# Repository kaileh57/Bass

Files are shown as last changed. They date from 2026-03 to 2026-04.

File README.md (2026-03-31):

This is a precision fender-style electric bass designed by me!

It's got three knobs for volume, treble and bass, as well as a custom PCB for active sound managment, and a dual amp system to play audio to EITHER a 1/4" jack OR a standard 3.5mm headphone jack. 
It also has a small rechargable battery to let me play with my headphones away from an amp or power source for hopefully a few hours at a time. 

The bass is pretty standard, and if you wanna 3d print the two parts, buy all the components, the wiring diagram should get you through the complex part!

I made this as I don't currently have an electric bass to play on, and would really like the chance to make my own instrument and start playing new types of music!

Here's what it looks like assembled:



The PCB



Wiring diagram:


The bom can be found in the bom.csv!

This was made (JUST IN TIME) for hack clubs blueprint program, which has been awesome!

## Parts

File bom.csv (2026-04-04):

Part Name | Quantity | Price (USD) | Source | Link | Notes
JLCPCB PCB Order (90x80mm 2-layer FR4 x5) | 1 | $7.18 | JLCPCB | https://jlcpcb.com/ | Incl. shipping + tax. Global Standard Direct Line
OPA2134PA DIP-8 (U1) | 1 | $6.98 | LCSC | https://www.lcsc.com/product-detail/C1346118.html?
NJM4556AD DIP-8 (U2) | 1 | $0.51 | LCSC | https://www.lcsc.com/product-detail/C2838125.html
TLE2426CLP TO-92 (U3) | 1 | $3.36 | Digikey | https://www.digikey.com/en/products/detail/texas-instruments/TLE2426CLP/276234
DIP-8 IC Sockets | 2 | $1.84 | LCSC | https://www.lcsc.com/product-detail/C2874007.html | For U1 and U2
1N5819 Schottky Diode DO-41 (D1) | 1 | $0.59 | LCSC | https://www.lcsc.com/product-detail/C402218.html | Reverse polarity protection
100uH Radial Power Inductor (L1) | 1 | $1.54 | LCSC | https://www.lcsc.com/product-detail/C5119631.html | Drum-core. 200mA+ sat current. DCR under 2 ohm
Resistor 0R axial (R_in_prot + R_damp) | 2 | $8.17 | LCSC | Kit: https://www.aliexpress.us/item/3256806831693280.html | Wire links. 1/4W axial through-hole
Resistor 2.2R axial (R_stab) | 1 | Included | LCSC |  | 1/4W metal film
Resistor 10R axial (R8 + R11) | 2 | Included | LCSC |  | 1/4W metal film
Resistor 100R axial (R2 + R_bias) | 2 | Included | LCSC |  | 1/4W metal film
Resistor 2.2K axial (R_LED) | 1 | Included | LCSC |  | 1/4W metal film
Resistor 10K axial (x10) | 10 | Included | LCSC |  | R_flat_in/fb R_treble1/2 R_fb1/2 R_gain1/2 R_bleed1/2
Resistor 22K axial (x3) | 3 | Included | LCSC |  | R_bass1/2 R_treble3
Resistor 470K axial (x2) | 2 | Included | LCSC |  | R_bias_hp1/2
Resistor 1M axial (R1) | 1 | Included | LCSC |  | Buffer input bias
100nF Ceramic Disc Cap 50V (x6) | 6 | $1.38 | AliExpress | https://www.aliexpress.us/item/3256805724293323.html | C2 C4 C_byp_U1 C_byp_U2 C_vref_U1 C_vref_U2. 5mm pitch
1nF Ceramic Disc Cap (C_bias) | 1 | $1.63 | AliExpress | https://www.aliexpress.us/item/3256802327709422.html | 5mm pitch, 1000pf
100uF 25V Electrolytic Radial (x3) | 3 | $0.56 | LCSC | https://www.lcsc.com/product-detail/C47344175.html | C1 C_pwr_U1 C_pwr_U2. 3.5mm pitch
1000uF 10V Electrolytic Radial (C3) | 1 | $0.61 | LCSC | https://www.lcsc.com/product-detail/C49256787.html | VREF reservoir. 5mm lead spacing
470uF 10V Electrolytic Radial (x2) | 2 | $0.78 | LCSC | https://www.lcsc.com/product-detail/C51904456.html | C_hp_out1 C_hp_out2. 5mm pitch
1uF Film Cap (x3) | 3 | $4.20 | AliExpress | https://www.aliexpress.us/item/3256806983416179.html | C_in C_hp_in1 C_hp_in2. 5mm pitch polyester, Color: 100v 0.1uF 5P
1nF Film Cap (C_treble) | 1 | $1.53 | AliExpress | https://www.aliexpress.us/item/3256808657561743.html | Treble wiper series cap. 5mm pitch
2.2uF Film Cap (C_vol) | 1 | $4.26 | AliExpress | https://www.aliexpress.us/item/3256803936423484.html | EQ output AC coupling. 10mm ish pitch
47nF Film Cap (C_bass) | 1 | $2.98 | AliExpress | https://www.aliexpress.us/item/3256808657558959.html | OFF-BOARD: soldered across bass pot lugs pin1-pin3
Pin Header Strip 1x40 2.54mm | 1 | $0.74 | LCSC | https://www.lcsc.com/product-detail/C2337.html | Cut to size for 9 connectors (26 pins total)
MT3608 DC-DC Boost Converter Module | 1 | $4.33 | AliExpress | https://www.aliexpress.us/item/3256811342611791.html | Boosts 3.7V to 9V.
TP4056 USB-C Li-Ion Charging Module | 1 | $6.42 | AliExpress | https://www.aliexpress.us/item/3256807940520587.html | USB-C charger with protection.
18650 Battery Holder (single cell) | 1 | $2.11 | AliExpress | https://www.aliexpress.us/item/3256809280893834.html? | Single cell holder with wire leads
DPDT Toggle Switch ON-ON 6-pin | 1 | $3.73 | AliExpress | https://www.aliexpress.us/item/2251832829462679.html | Active/passive bypass. Measure dims before CAD
LED 3mm | 1 | $0.00 | I have LEDs |  | Power indicator. Off-board via header
Adhesive Copper Foil Tape | 1 | $2.64 | AliExpress | https://www.aliexpress.us/item/3256802931706214.html | EMI shielding for control cavity
22AWG Stranded Hookup Wire | 1 | $0.00 | From previous project |  | Off-board wiring: pots/pickup/jacks/switch/bridge ground
Seymour Duncan SPB-1 Vintage P-Bass Pickup | 1 | $99.00 | Amazon | https://www.amazon.com/Seymour-Duncan-SPB-1-Vintage-Split-coil/dp/B001FXQDVQ | Split-coil P-bass pickup
Gotoh 201B-4 Bass Bridge (Chrome) | 1 | $46.49 | Amazon | https://www.amazon.com/GOTOH-201B-4-4-String-Bridge-spacing/dp/B00FGUN948 | 4-string. Includes mounting screws
CTS 250K Audio Taper Pot (A250K) | 1 | $13.88 | Amazon | https://www.amazon.com/A250K-Standard-Potentiometer-Electric-Guitar/dp/B0DSW4B33P?s=musical-instruments | Volume pot. LONG SHAFT if 12mm body face
100K Linear Pot B100K (x2) | 2 | $9.99 | Amazon | https://www.amazon.com/TWTADE-Potentiometer-Single-Variable-Aluminum/dp/B07DHGR3ST | Bass + Treble EQ pots. Long shaft preferred
Switchcraft #L11 Mono 1/4in Output Jack | 1 | 6.99 | Amazon | https://www.amazon.com/Switchcraft-2-Conductor-Input-Circuit-Bushing/dp/B0049BMPFO | Line output. 3/8-32 thread. 9.53mm hole
3.5mm Panel Mount Stereo Jack | 1 | $5.99 | Amazon | https://www.amazon.com/BLLNDX-Stereo-Female-Headphone-Connector/dp/B09B7JKSQ1?s=electronics | Headphone output. Measure before finalizing CAD hole
Schaller S-Locks Strap Locks (Pair Chrome) | 1 | $32.49 | Amazon | https://www.amazon.com/Schaller-Locks-Guitar-Buttons-Chrome/dp/B07F7DSBYW | Size M 4.0mm thread for PA6-CF body
Fender-Style Bass Neck Plate (4-bolt) | 1 | $11.49 | Amazon | https://www.amazon.com/Fender-4-Bolt-Vintage-Style-Plate-Plain/dp/B0002KZF8U | Distributes bolt force on 3D-printed body
18650 Li-Ion Battery | 1 | $7.74 | AliExpress | https://www.aliexpress.us/item/3256811753613609.html | 3.7V rechargeable.
Bass Guitar Strings 45-105 | 1 | $0.00 | Will get in person |  | Standard 34in scale roundwound
Pot Knobs 1/4in Solid Shaft (set of 3+) | 1 | $7.64 | Amazon | https://www.amazon.com/gonymask-Control-Telecaster-PaulGuitar-Accessories/dp/B0F64W28K5 | For volume + bass + treble pots
M3 Heat-Set Inserts (50 pack) | 1 | $0.00 | From previous project |  | Bridge(5) pickup(4) covers(~12) battery(4). ~25 needed
M4 Heat-Set Inserts (10+ pack) | 1 | $0.00 | From previous project |  | Neck mounting x4. M4 x 12mm depth
M3 Machine Screws Assorted Kit | 1 | $9.99 | Amazon | amazon.com/Fgruh-750PCS-Assortment-Washers-Assorted/dp/B0FGV5FCBN/ref=sr_1_1_sspa?dib=eyJ2IjoiMSJ9.TEeF4awxyePoe3vNhqiBQr0P_DmHv8ymUY8Qqx9WQ1FUXAzHaqn7Y8y5g9azicuwQtHiXo6NQLmPv56URUvkhMUymaUDJFJvw-HmGF4NkiRx3JDhtSwcc84dLESBAIK-02oN7P5qS4EYkA_d_vIJnD2VUQ23f98Jo7s_LfoW4BGmwW6VNMbu751flLsCLy78MkTjO58lVkEH-jfCIarzY39CZAPClaqvW_Afgxvuag4.491EHZPTOLb2_PdZ3IK-6gZMYVEv3uiP9oqsxlO1m2U&dib_tag=se&keywords=M3+machine+screw+assortment+kit&qid=1774975024&sr=8-1-spons&sp_csd=d2lkZ2V0TmFtZT1zcF9hdGY&psc=1 | Bridge + pickup + cavity cover mounting
M4 x 45mm Machine Screws (x4) | 4 | $2.96 | AliExpress | https://www.aliexpress.us/item/3256804067895917.html | m4 x 45
Gorilla 2-Part Epoxy | 1 | $5.97 | Amazon | https://www.amazon.com/Gorilla-Part-Epoxy-Minute-ounce/dp/B001Z3C3AG?th=1 | Bonding center piece to wing pieces
Micro-Mesh Sanding Kit | 1 | $18.19 | Amazon | https://www.amazon.com/Micro-Mesh-Pen-Sanding-Kit/dp/B0037MEIT2 | Finishing wood PLA. 220-1500 grit
Danish Oil (pint) | 1 | $0.00 | Borrowed from teacher |  | Finish for wood PLA wings
PA6-CF Filament (center piece) | 1 | $0.00 | Printing Legion
Wood PLA Filament (wings) | 1 | $0.00 | Printing Legion
Warmoth P-Bass Neck (4-string 34in scale) | 1 | $0.00 | Donated | https://warmoth.com | Donated by Warmoth Guitar Products. Standard Fender P-bass geometry

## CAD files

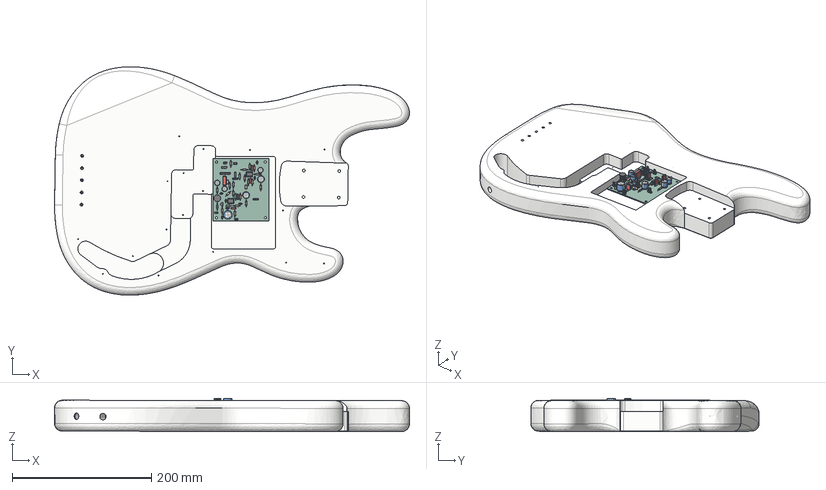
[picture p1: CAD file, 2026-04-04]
CAD/Assemble.step
510.2 x 328.2 x 47.8 mm
C_Rect_L7.2mm_W2.5mm_P5.00mm_FKS2_FKP2_MKS2_MKP2 x 4
R_Axial_DIN0207_L6.3mm_D2.5mm_P10.16mm_Horizontal x 24
C_Rect_L13.5mm_W5.0mm_P10.00mm_FKS3_FKP3_MKS4
CP_Radial_D8.0mm_P3.50mm x 3
C_Disc_D5.0mm_W2.5mm_P5.00mm x 7
PinHeader_1x06_P2.54mm_Vertical
DIP-8_W7.62mm x 2
PinHeader_1x03_P2.54mm_Vertical x 4
CP_Radial_D10.0mm_P5.00mm x 2
D_DO-41_SOD81_P10.16mm_Horizontal
L_Radial_D10.0mm_P5.00mm_Fastron_07M
PinHeader_1x02_P2.54mm_Vertical x 4
CP_Radial_D12.5mm_P5.00mm
TO-92_Inline
bass_PCB

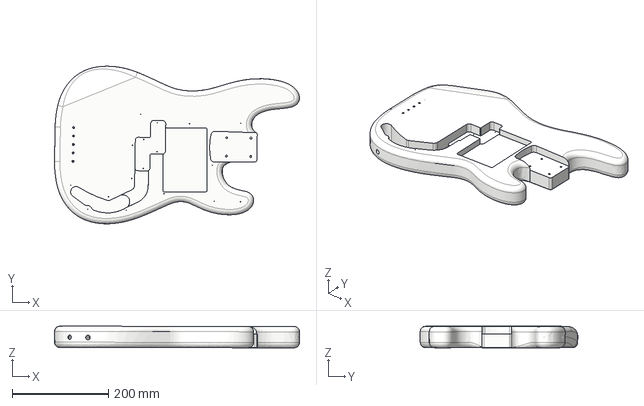
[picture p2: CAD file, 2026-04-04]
CAD/Body.step
510.2 x 328.2 x 45.1 mm

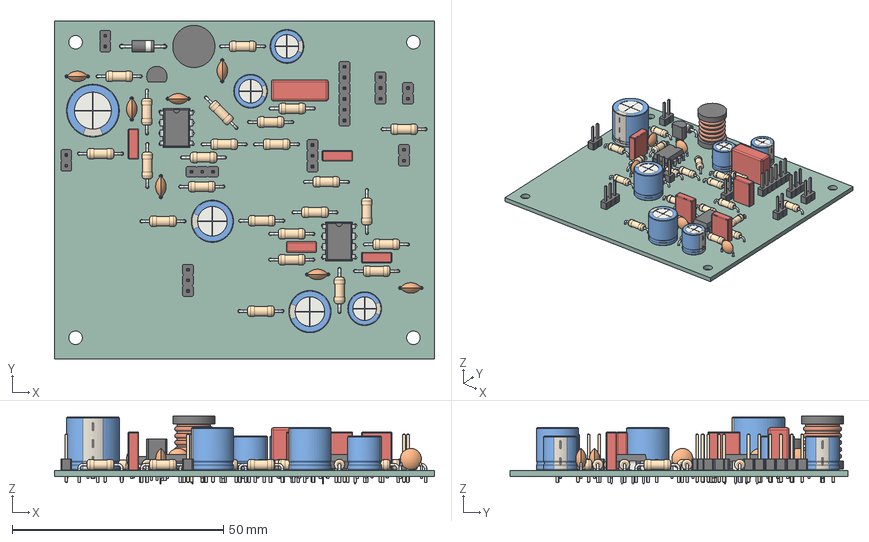
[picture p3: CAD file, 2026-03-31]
PCB/pcb.step
90.0 x 80.0 x 16.1 mm
C_Rect_L7.2mm_W2.5mm_P5.00mm_FKS2_FKP2_MKS2_MKP2 x 4
R_Axial_DIN0207_L6.3mm_D2.5mm_P10.16mm_Horizontal x 24
C_Rect_L13.5mm_W5.0mm_P10.00mm_FKS3_FKP3_MKS4
CP_Radial_D8.0mm_P3.50mm x 3
C_Disc_D5.0mm_W2.5mm_P5.00mm x 7
PinHeader_1x06_P2.54mm_Vertical
DIP-8_W7.62mm x 2
PinHeader_1x03_P2.54mm_Vertical x 4
CP_Radial_D10.0mm_P5.00mm x 2
D_DO-41_SOD81_P10.16mm_Horizontal
L_Radial_D10.0mm_P5.00mm_Fastron_07M
PinHeader_1x02_P2.54mm_Vertical x 4
CP_Radial_D12.5mm_P5.00mm
TO-92_Inline
bass_PCB

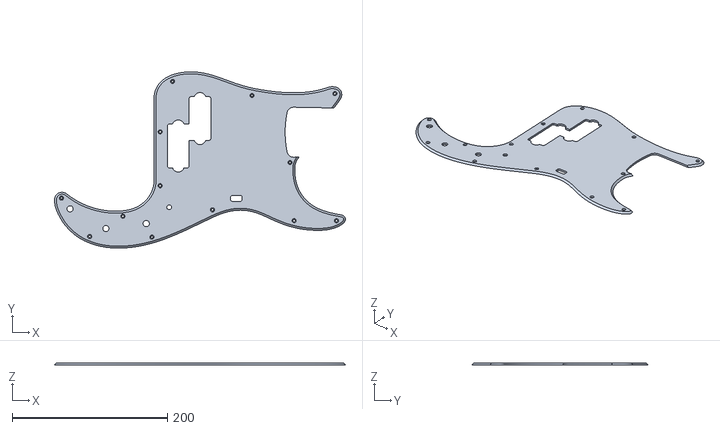
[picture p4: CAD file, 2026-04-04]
Production/CAD/Pickguard.stl
374.4 x 226.8 x 2.50

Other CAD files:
Production/CAD/Body.stl
CAD/Pickguard.step

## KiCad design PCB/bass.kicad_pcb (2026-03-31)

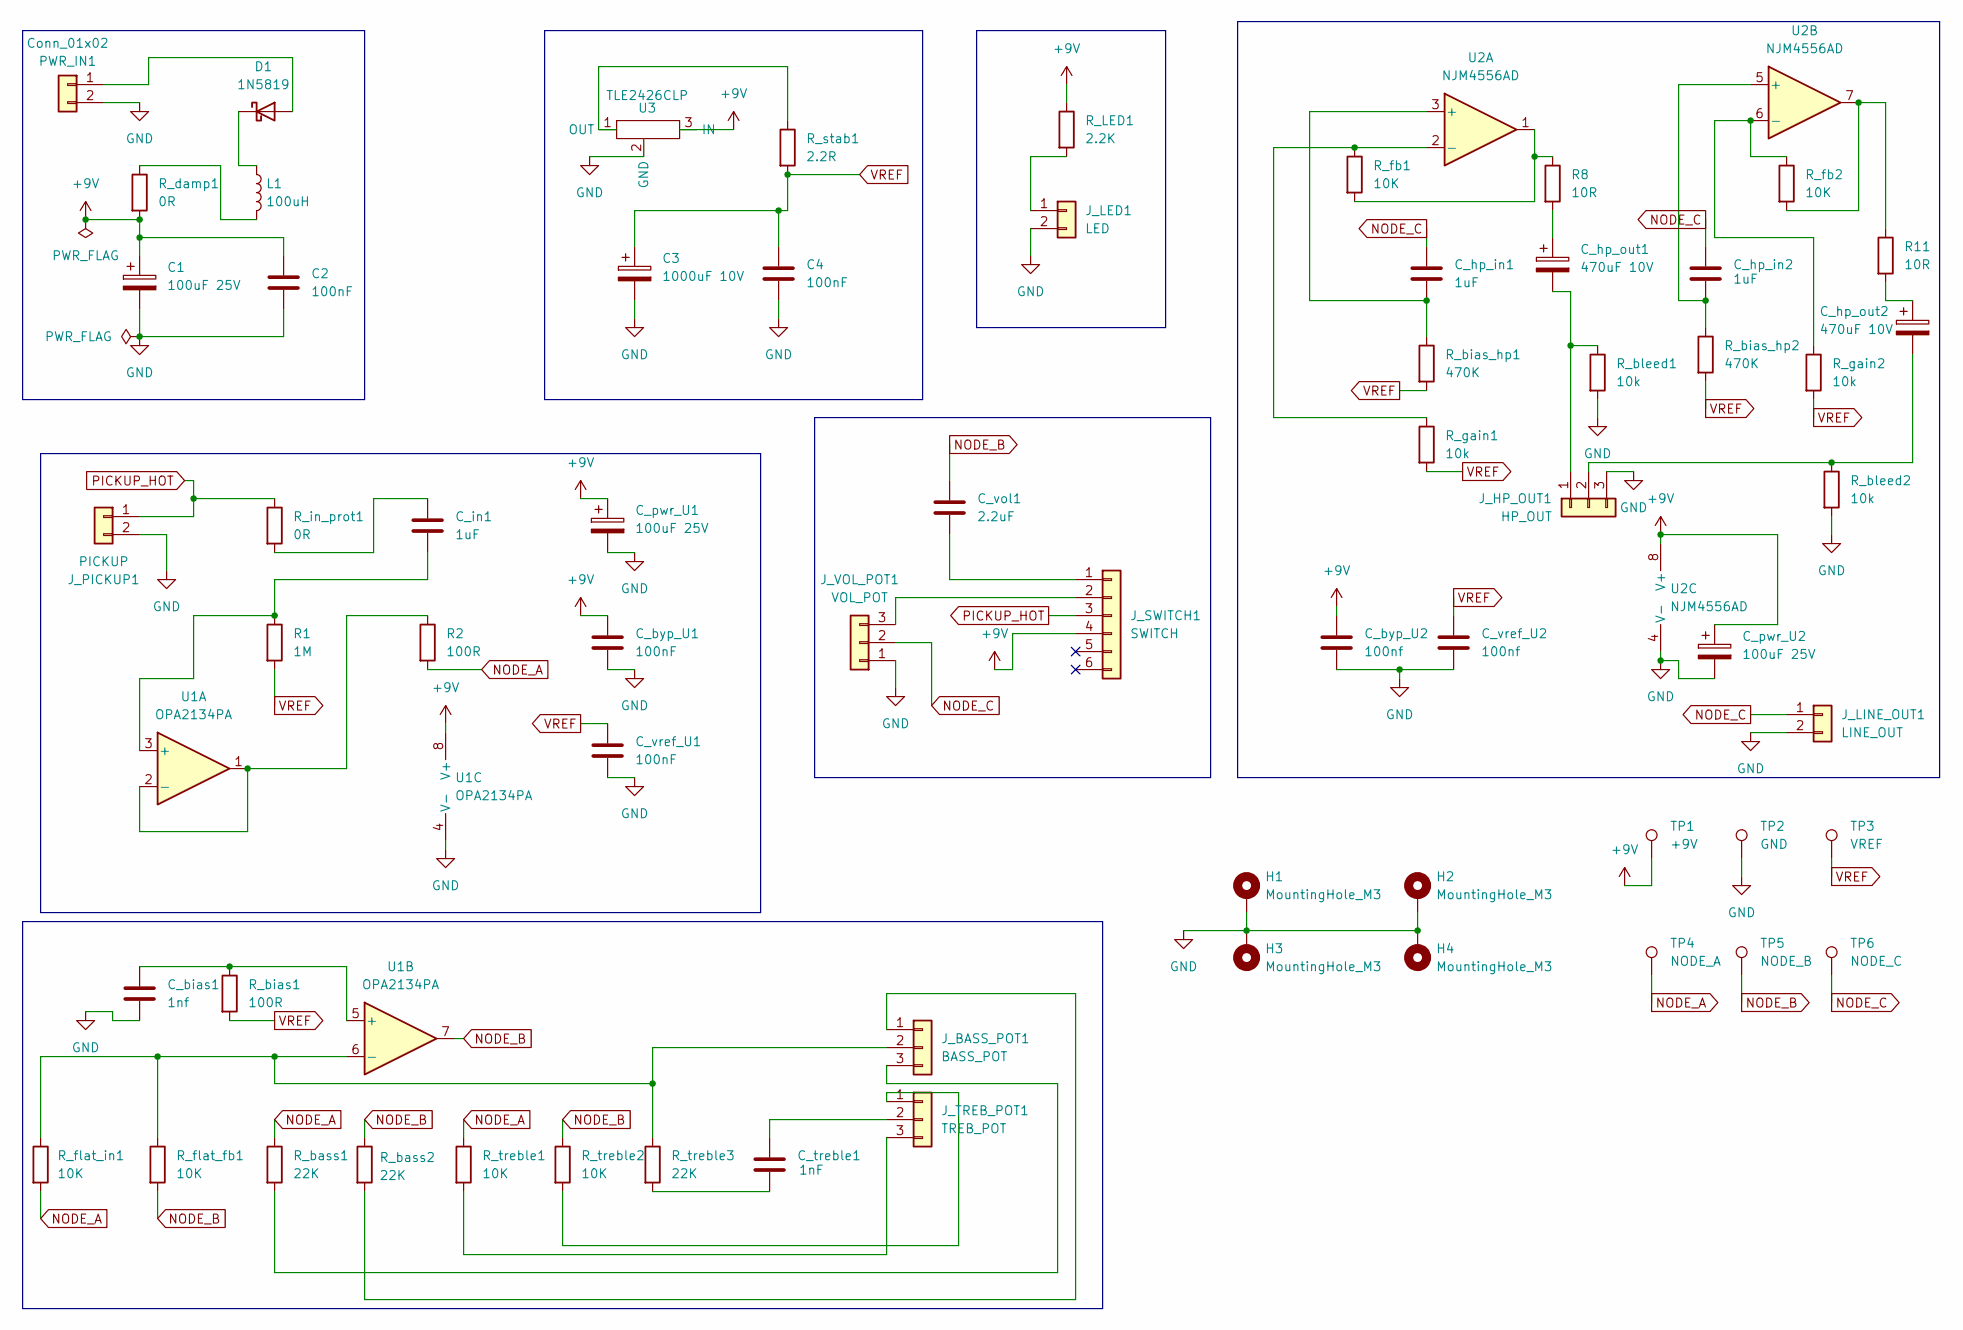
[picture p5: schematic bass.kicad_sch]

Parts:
C1: 100uF 25V; CP_Radial_D8.0mm_P3.50mm
C2, C4: 100nF; C_Disc_D5.0mm_W2.5mm_P5.00mm
C3: 1000uF 10V; CP_Radial_D12.5mm_P5.00mm
C_bias1: 1nf; C_Disc_D5.0mm_W2.5mm_P5.00mm
C_byp_U1: 100nF; C_Disc_D5.0mm_W2.5mm_P5.00mm
C_byp_U2: 100nf; C_Disc_D5.0mm_W2.5mm_P5.00mm
C_hp_in1, C_hp_in2: 1uF; C_Rect_L7.2mm_W2.5mm_P5.00mm_FKS2_FKP2_MKS2_MKP2
C_hp_out1, C_hp_out2: 470uF 10V; CP_Radial_D10.0mm_P5.00mm
C_in1: 1uF; C_Rect_L7.2mm_W2.5mm_P5.00mm_FKS2_FKP2_MKS2_MKP2
C_pwr_U1, C_pwr_U2: 100uF 25V; CP_Radial_D8.0mm_P3.50mm
C_treble1: 1nF; C_Rect_L7.2mm_W2.5mm_P5.00mm_FKS2_FKP2_MKS2_MKP2
C_vol1: 2.2uF; C_Rect_L13.5mm_W5.0mm_P10.00mm_FKS3_FKP3_MKS4
C_vref_U1: 100nF; C_Disc_D5.0mm_W2.5mm_P5.00mm
C_vref_U2: 100nf; C_Disc_D5.0mm_W2.5mm_P5.00mm
D1: 1N5819; D_DO-41_SOD81_P10.16mm_Horizontal
H1, H2, H3, H4: MountingHole_M3; MountingHole_3.2mm_M3_Pad
J_BASS_POT1: BASS_POT; PinHeader_1x03_P2.54mm_Vertical
J_HP_OUT1: HP_OUT; PinHeader_1x03_P2.54mm_Vertical
J_LED1: LED; PinHeader_1x02_P2.54mm_Vertical
J_LINE_OUT1: LINE_OUT; PinHeader_1x02_P2.54mm_Vertical
J_PICKUP1: PICKUP; PinHeader_1x02_P2.54mm_Vertical
J_SWITCH1: SWITCH; PinHeader_1x06_P2.54mm_Vertical
J_TREB_POT1: TREB_POT; PinHeader_1x03_P2.54mm_Vertical
J_VOL_POT1: VOL_POT; PinHeader_1x03_P2.54mm_Vertical
L1: 100uH; L_Radial_D10.0mm_P5.00mm_Fastron_07M
PWR_IN1: Conn_01x02; PinHeader_1x02_P2.54mm_Vertical
R1: 1M; R_Axial_DIN0207_L6.3mm_D2.5mm_P10.16mm_Horizontal
R2: 100R; R_Axial_DIN0207_L6.3mm_D2.5mm_P10.16mm_Horizontal
R8, R11: 10R; R_Axial_DIN0207_L6.3mm_D2.5mm_P10.16mm_Horizontal
R_LED1: 2.2K; R_Axial_DIN0207_L6.3mm_D2.5mm_P10.16mm_Horizontal
R_bass1, R_bass2: 22K; R_Axial_DIN0207_L6.3mm_D2.5mm_P10.16mm_Horizontal
R_bias1: 100R; R_Axial_DIN0207_L6.3mm_D2.5mm_P10.16mm_Horizontal
R_bias_hp1, R_bias_hp2: 470K; R_Axial_DIN0207_L6.3mm_D2.5mm_P10.16mm_Horizontal
R_bleed1, R_bleed2: 10k; R_Axial_DIN0207_L6.3mm_D2.5mm_P10.16mm_Horizontal
R_damp1: 0R; R_Axial_DIN0207_L6.3mm_D2.5mm_P10.16mm_Horizontal
R_fb1, R_fb2: 10K; R_Axial_DIN0207_L6.3mm_D2.5mm_P10.16mm_Horizontal
R_flat_fb1: 10K; R_Axial_DIN0207_L6.3mm_D2.5mm_P10.16mm_Horizontal
R_flat_in1: 10K; R_Axial_DIN0207_L6.3mm_D2.5mm_P10.16mm_Horizontal
R_gain1, R_gain2: 10k; R_Axial_DIN0207_L6.3mm_D2.5mm_P10.16mm_Horizontal
R_in_prot1: 0R; R_Axial_DIN0207_L6.3mm_D2.5mm_P10.16mm_Horizontal
R_stab1: 2.2R; R_Axial_DIN0207_L6.3mm_D2.5mm_P10.16mm_Horizontal
R_treble1, R_treble2: 10K; R_Axial_DIN0207_L6.3mm_D2.5mm_P10.16mm_Horizontal
R_treble3: 22K; R_Axial_DIN0207_L6.3mm_D2.5mm_P10.16mm_Horizontal
TP1: +9V; TestPoint_Pad_2.0x2.0mm
TP2: GND; TestPoint_Pad_2.0x2.0mm
TP3: VREF; TestPoint_Pad_2.0x2.0mm
TP4: NODE_A; TestPoint_Pad_2.0x2.0mm
TP5: NODE_B; TestPoint_Pad_2.0x2.0mm
TP6: NODE_C; TestPoint_Pad_2.0x2.0mm
U1: OPA2134PA; DIP-8_W7.62mm
U2: NJM4556AD; DIP-8_W7.62mm
U3: TLE2426CLP; TO-92_Inline

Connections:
+9V: C1.1, C2.1, C_byp_U1.1, C_byp_U2.1, C_pwr_U1.1, C_pwr_U2.1, J_SWITCH1.4, R_LED1.1, R_damp1.2, TP1.1, U1.8 (V+), U2.8 (V+), U3.3 (IN)
GND: C1.2, C2.2, C3.2, C4.2, C_bias1.2, C_byp_U1.2, C_byp_U2.2, C_pwr_U1.2, C_pwr_U2.2, C_vref_U1.2, C_vref_U2.2, H1.1, H2.1, H3.1, H4.1, J_HP_OUT1.3, J_LED1.2, J_LINE_OUT1.2, J_PICKUP1.2, J_VOL_POT1.1, PWR_IN1.2, R_bleed1.2, R_bleed2.2, TP2.1, U1.4 (V-), U2.4 (V-), U3.2 (GND)
NODE_A: R2.2, R_bass1.1, R_flat_in1.2, R_treble1.1, TP4.1
NODE_B: C_vol1.1, R_bass2.1, R_flat_fb1.2, R_treble2.1, TP5.1, U1.7
NODE_C: C_hp_in1.1, C_hp_in2.1, J_LINE_OUT1.1, J_VOL_POT1.2, TP6.1
unnamed: C_hp_out1.1, R8.2
unnamed: C_hp_out2.1, R11.2
unnamed: C_in1.1, R_in_prot1.2
unnamed: C_treble1.2, R_treble3.2
unnamed: D1.2 (A), PWR_IN1.1
unnamed: D1.1 (K), L1.1
unnamed: J_BASS_POT1.1, R_bass2.2
unnamed: J_BASS_POT1.2, R_flat_fb1.1, R_flat_in1.1, R_treble3.1, U1.6 (-)
unnamed: J_BASS_POT1.3, R_bass1.2
unnamed: C_hp_out1.2, J_HP_OUT1.1, R_bleed1.1
unnamed: C_hp_out2.2, J_HP_OUT1.2, R_bleed2.1
unnamed: J_LED1.1, R_LED1.2
unnamed: C_vol1.2, J_SWITCH1.1
unnamed: J_SWITCH1.2, J_VOL_POT1.3
unnamed: J_TREB_POT1.1, R_treble2.2
unnamed: C_treble1.1, J_TREB_POT1.2
unnamed: J_TREB_POT1.3, R_treble1.2
unnamed: L1.2, R_damp1.1
unnamed: R8.1, R_fb1.2, U2.1
unnamed: R11.1, R_fb2.2, U2.7
unnamed: C_in1.2, R1.1, U1.3 (+)
unnamed: R2.1, U1.1, U1.2 (-)
unnamed: C_bias1.1, R_bias1.1, U1.5 (+)
unnamed: C_hp_in1.2, R_bias_hp1.1, U2.3 (+)
unnamed: R_fb1.1, R_gain1.1, U2.2 (-)
unnamed: C_hp_in2.2, R_bias_hp2.1, U2.5 (+)
unnamed: R_fb2.1, R_gain2.1, U2.6 (-)
unnamed: R_stab1.1, U3.1 (OUT)
PICKUP_HOT: J_PICKUP1.1, J_SWITCH1.3, R_in_prot1.1
VREF: C3.1, C4.1, C_vref_U1.1, C_vref_U2.1, R1.2, R_bias1.2, R_bias_hp1.2, R_bias_hp2.2, R_gain1.2, R_gain2.2, R_stab1.2, TP3.1

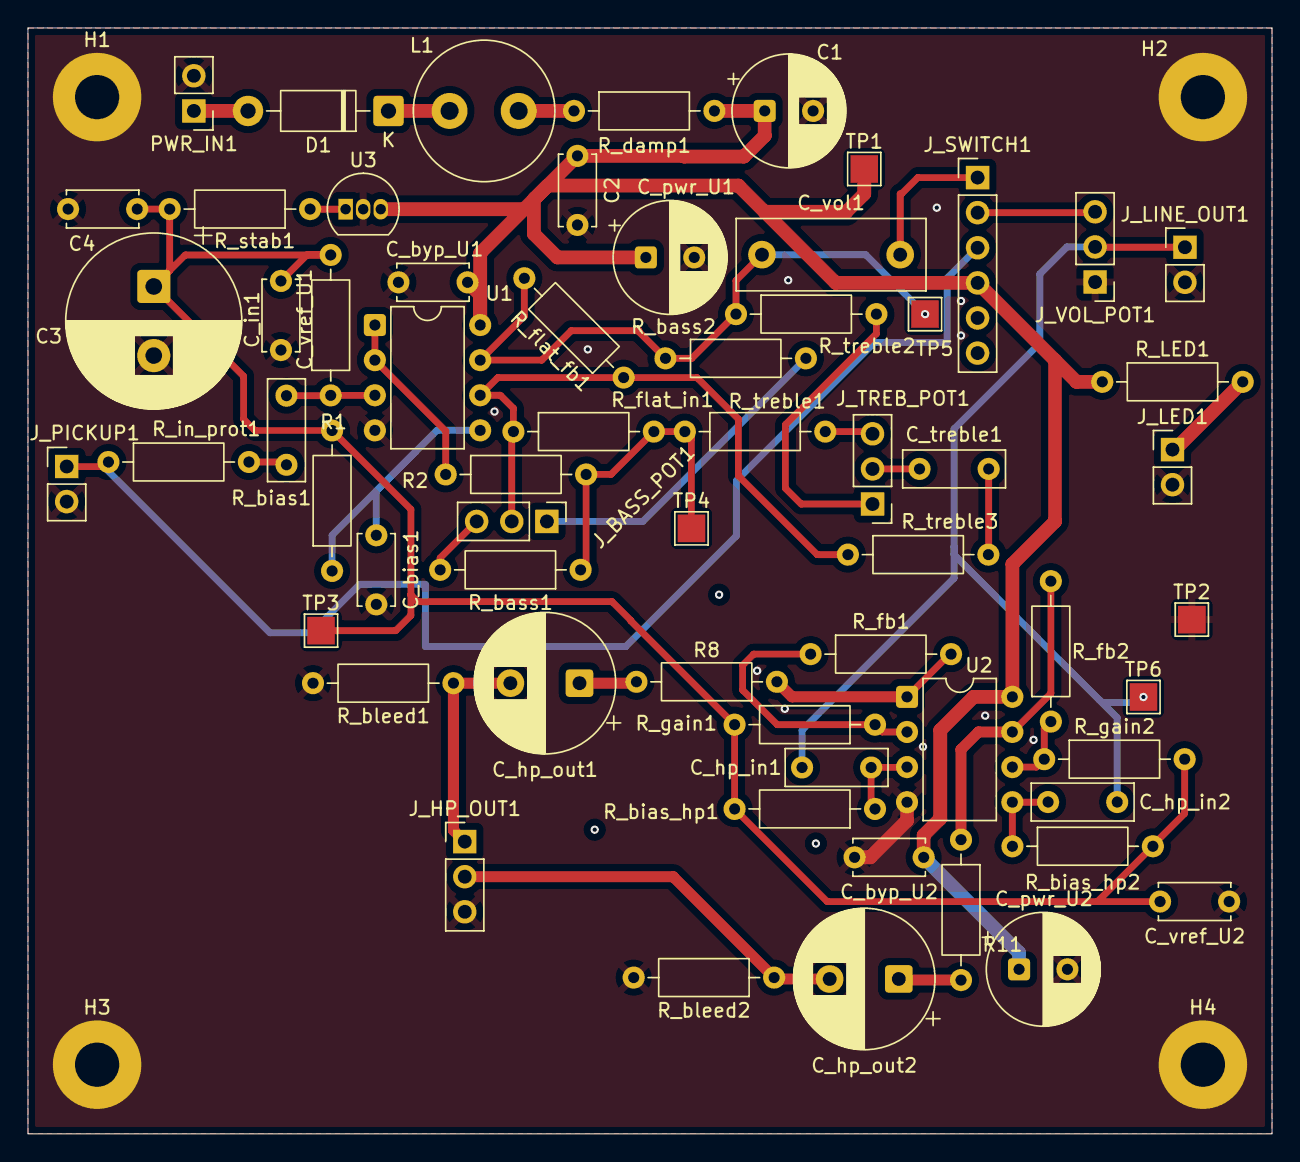
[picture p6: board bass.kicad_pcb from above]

Board: 2 copper layers, 90.0 x 80.0 mm, 66 parts (0 on the bottom side), 35 nets.

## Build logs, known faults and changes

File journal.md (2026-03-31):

<!--
  This journal is auto generated by Hack Club Blueprint.
-->

# 2/21/2026 - Did the schematic  

_Time spent: 5.0h_  

I've spent all week (midwinter break) researching and reading about allllll the different parts I'm gonna need for this, and hopefully I've got them all. 

Doing 100% through hole soldering to reduce cost and also give me more chances to make mistake (5 boards from jlcpcb).

Made a custom symbol too which was fun. Since this is like audio stuff and i'm wayyyy out of my depth im basically just praying i get a sound out of it. 



# 3/12/2026 - Wired everything up, many design iterations  

_Time spent: 4.0h_  



Ok its been a while and while the final components ended up being pretty much the same as I started, I have redone it several times due to audio quality concerns of some people I know, hopefully THIS should sound good!

# 3/15/2026 - Assigned footprints and pacified the ERC  

_Time spent: 3.0h_  



ERC was SUPER mad after the first pass at wiring, and I def had a few things wrong here and there, so I fixed that and ALSO assigned footprints! Going no SMD on this one to speed up the process, but there's still SO MUCH checking datasheets istg. 

# 3/22/2026 - Start of routing!  

_Time spent: 2.0h_  



Probably about halfway through the routing process! I'm locking in now to get the design finished by the end of the week for the blueprint deadline! Should be doable  

# 3/25/2026 - Added a few more things and minor wiring refac  

_Time spent: 2.0h_  



Some changes to a few footprints and placements to improve signal integrity, as well as a tiny bit more progress in wiring, hopefully tomorrow? I should be able to finish up the board and move on to the 3d modeling.  

# 3/29/2026 - Finished the PCB! and solved ERC  

_Time spent: 3.0h_  



Fought with the erc for a few hours, but it all works now, signal integrity SHOULD all work fine, and everything should be great and awesome and sound good  

# 3/30/2026 8 PM - Signal integrity improvments and some work on the 3d model!  

_Time spent: 5.0h_  




I think I have MOST of the shape I want? but im still working through some challenges with specific placement of components and such. Also, I have no idea how much time ive spent on this project tbh cuz i just realized the hours tracker is wayyyyy lower than the real time ive spent 💀💀💀oh well i dont think it matters

# 3/30/2026 11 PM - Refinement to the 3d model!  

_Time spent: 2.0h_  



3d model is near done I think, theres some issues with smoothing the top lip still, but ill fix that and then wrap up and submit soon! it really came together well in the end  

# 3/31/2026 - All done!!  

_Time spent: 5.0h_  

The 3d model is polished and all finshed up, ready for production

I created all the production files and other requirements got cart screenshots, and will be submitting now!



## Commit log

2026-02-22 move all the files into the repo
    [bass.kicad_pcb, bass.kicad_sch]
2026-03-31 some more work
    [bass.kicad_pcb, bass.step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]
2026-03-31 remaining project files
    [Assemble.step, Body.step, Body.stl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]
2026-03-31 Add wiring diagram to README
    Added wiring diagram image to the README.
2026-04-04 Replace Switchcraft output jack with new model
    Updated the output jack entry in the BOM to a new model and adjusted the price.
    [bom.csv]
2026-04-04 moved headphone jack
    [Assemble.step, Body.step, Body.stl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]
